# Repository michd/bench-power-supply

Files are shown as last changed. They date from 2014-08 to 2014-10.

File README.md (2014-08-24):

# Bench power supply

I'm working (currently just researching and prototyping) on developing my own bench power supply. This repository will mostly act as a working directory before it gets anywhere near completion, so expect stuff to move around a lot.

## Some requirements / desired features for the supply:

- DC output voltage of 1.5V - 35V (ish)
- Output current of up to 2.5~3A (ish)
- Voltage and current limit digitally adjustable, probably through rotary encoders
- Present output voltage and current displayed on LED 7 segment displays
- Additional (LCD?) display for setting the voltage and current limit (definitely need a way to view the current limit when it's not being reached)
- Maybe some USB ports (3?) providing 5V / 1A per port.

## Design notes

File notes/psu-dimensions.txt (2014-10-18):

Dimensions as seen from front; 0,0 is in top left

## IO board

Width: 119.1mm
Height: 56.7mm

Holes spacing:
Horizontal (width-wise): 113mm
Vertical (height-wise): 51.4mm
Diameter: 2mm
Margin around holes: 3mm

## Power board

Width:  99.2mm
Height: 74.4mm

Hole spacing:
Horizontal (width-wise): 90.2mm
Vertical (height-wise): 67.3mm
Diameter: 3mm
Margin around holes: 3.3mm

## Controller board

Width: 77.8mm
Height: 67.4mm

Holes spacing:
Horizontal (width-wise): 71.4mm
Vertical (height-wise): 61.6mm
Diameter: 2mm
Margin around holes: 2.5mm

## Main transformer

Width: 89.10mm
Height: 75.0mm
Depth: 64.2mm
Screwhole bottom offset: 8.5mm
Narrow side screwhole side offset: 8.5mm
Wide side screwhole side offset: 15.5mm
screwhole width: 4.5mm
Through-holes locations: 57.25x70.5mm, d: 5mm

# Box

inner Width: 150mm
inside holes: 154mm x 90mm  spacing
hole diameter: 154mm

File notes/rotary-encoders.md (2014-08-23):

These are just some notes to self after a session of figuring out how to get a rotary encoder do what I want. Thanks for the help, @james147
# Working with rotary encoders

For reading rotary encoders for input, use the [ClickEncoder](https://github.com/0xPIT/encoder/tree/arduino) library.

This library relies on [TimerOne](https://code.google.com/p/arduino-timerone/).

Each (click) rotary encoder requires 3 pins on the uC, two for the rotary encoder, one for the button. These pins can be any ol' digital input.

In `void loop()`, poll check encoder->getValue() to get the integer increase/decrease since last time. Base the integration on the example that comes with the library.

The input pins get pulled up on the arduino board, but it might need external pull-up resistors w/o the arduino board.

Also, and remember this: **the common is the middle pin**.

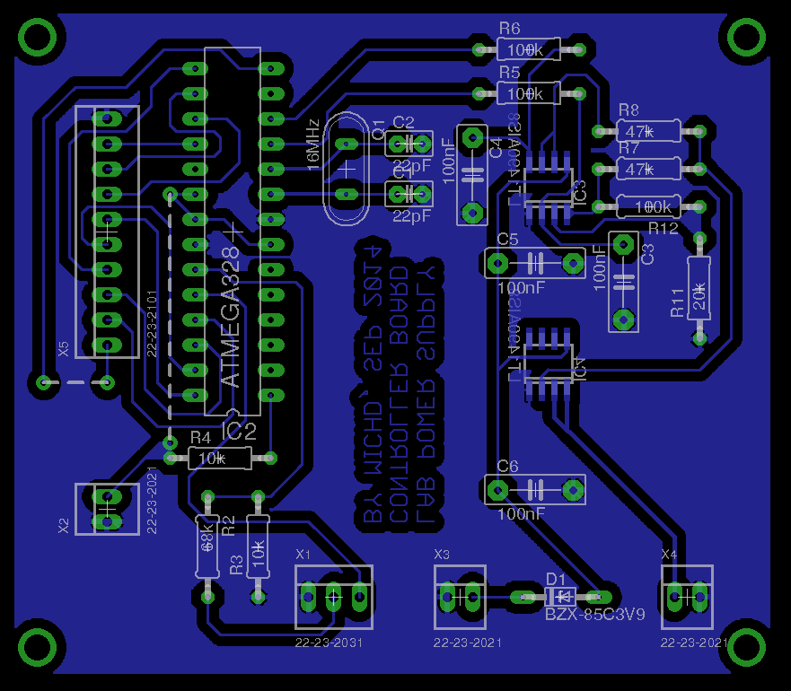
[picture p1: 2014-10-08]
eagle/controller_board_screenshot.png

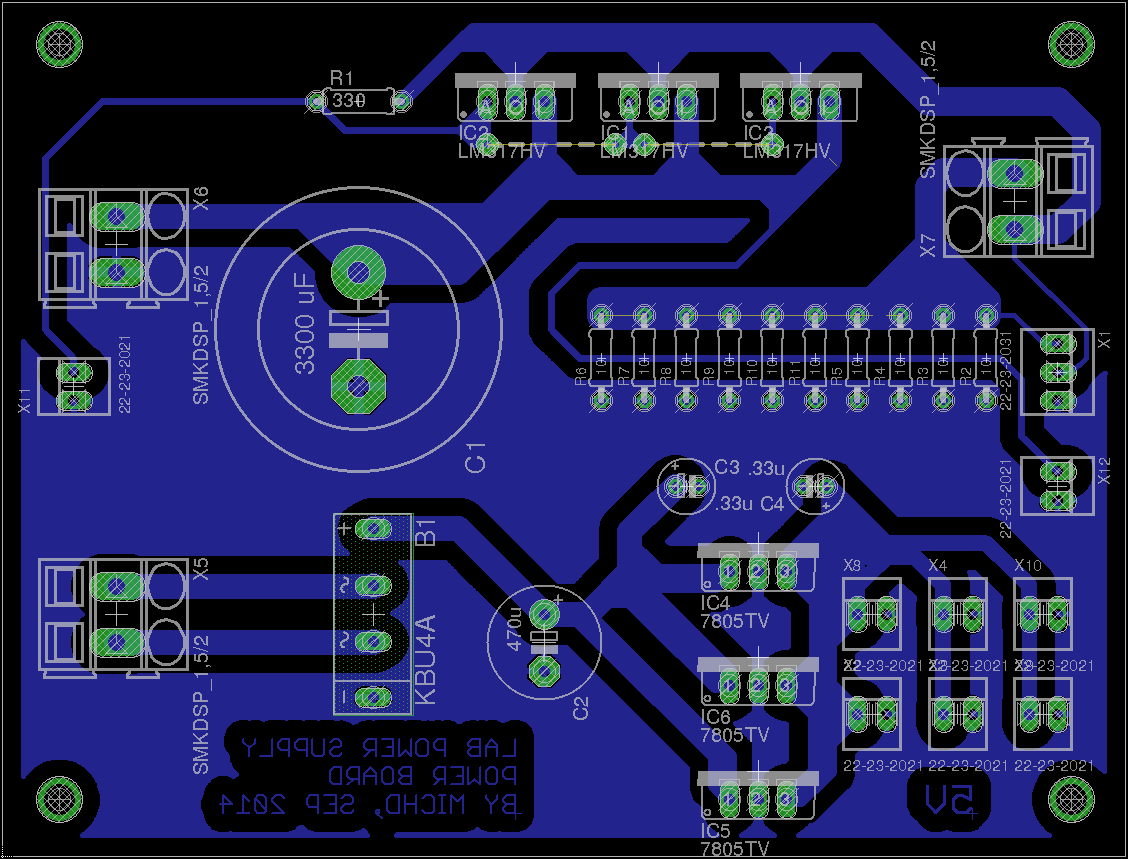
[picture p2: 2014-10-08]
eagle/power_board_screenshot.png

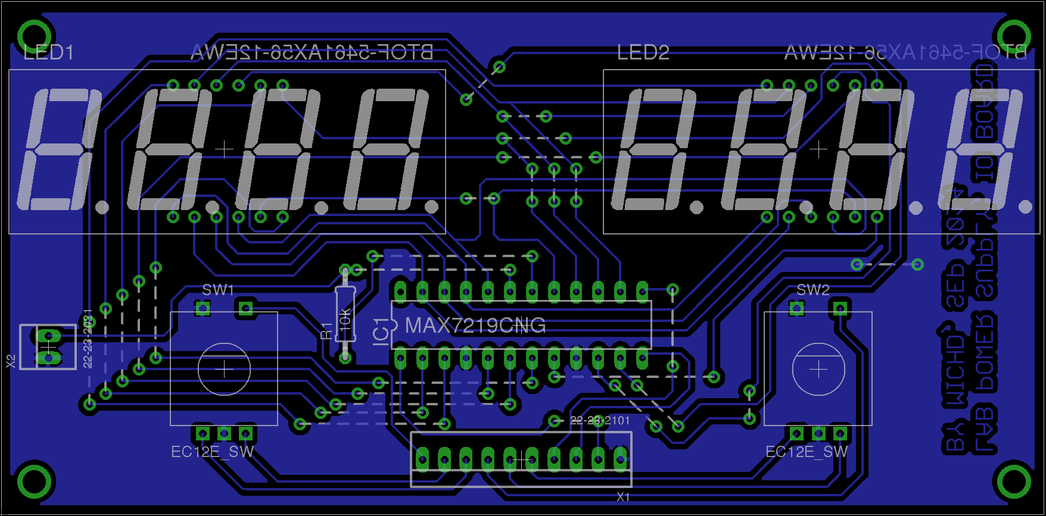
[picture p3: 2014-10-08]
eagle/io_board_screenshot.png

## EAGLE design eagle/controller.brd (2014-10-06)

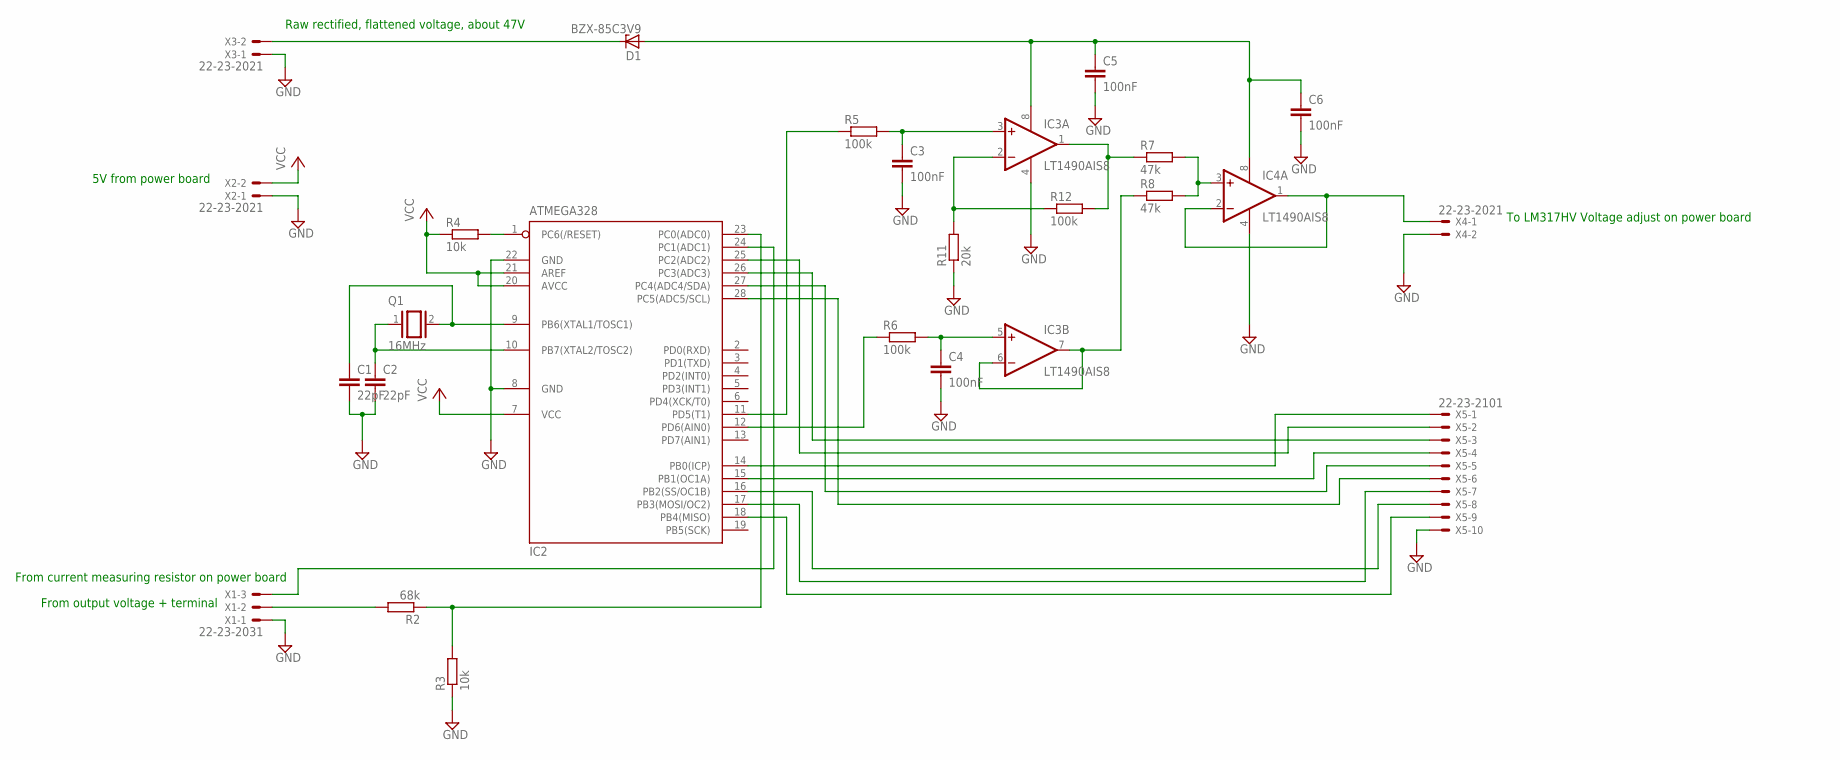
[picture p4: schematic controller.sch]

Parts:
C1, C2: 22pF; C2.5-2
C3, C4, C5, C6: 100nF; C7.5B3
D1: BZX-85C3V9; DO34Z7
IC2: ATMEGA328; DIL28-3
IC3, IC4: LT1490AIS8; SO08
Q1: 16MHz; QS
R2: 68k; 0207/10
R3, R4: 10k; 0207/10
R5, R6, R12: 100k; 0207/10
R7, R8: 47k; 0207/10
R11: 20k; 0207/10
X1: 22-23-2031
X2, X3, X4: 22-23-2021
X5: 22-23-2101

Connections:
GND: C1.2, C2.2, C3.2, C4.2, C5.2, C6.2, IC2.8 (GND), IC2.22 (GND), IC3.4 (V-), IC4.4 (V-), R3.1, R11.1, X1.1, X2.1, X3.1, X4.2, X5.10
unnamed: IC2.18 (PB4(MISO)), X5.9
unnamed: IC2.16 (PB2(SS/OC1B)), X5.8
unnamed: IC2.17 (PB3(MOSI/OC2)), X5.7
unnamed: IC2.7 (VCC), IC2.20 (AVCC), IC2.21 (AREF), R4.1, X2.2
unnamed: IC3.1 (OUT), R7.1, R12.2
unnamed: IC2.14 (PB0(ICP)), X5.1
unnamed: IC2.24 (PC1(ADC1)), X1.3
unnamed: IC2.23 (PC0(ADC0)), R2.1, R3.2
unnamed: R2.2, X1.2
unnamed: C1.1, IC2.9 (PB6(XTAL1/TOSC1)), Q1.2
unnamed: C2.1, IC2.10 (PB7(XTAL2/TOSC2)), Q1.1
unnamed: IC3.6 (-IN), IC3.7 (OUT), R8.1
unnamed: IC2.11 (PD5(T1)), R5.1
unnamed: IC2.1 (PC6(/RESET)), R4.2
unnamed: C3.1, IC3.3 (+IN), R5.2
unnamed: C4.1, IC3.5 (+IN), R6.2
unnamed: C5.1, C6.1, D1.A, IC3.8 (V+), IC4.8 (V+)
unnamed: IC2.12 (PD6(AIN0)), R6.1
unnamed: IC4.3 (+IN), R7.2, R8.2
unnamed: IC3.2 (-IN), R11.2, R12.1
unnamed: IC4.1 (OUT), IC4.2 (-IN), X4.1
unnamed: IC2.15 (PB1(OC1A)), X5.4
unnamed: IC2.25 (PC2(ADC2)), X5.2
unnamed: IC2.28 (PC5(ADC5/SCL)), X5.6
unnamed: IC2.27 (PC4(ADC4/SDA)), X5.5
unnamed: D1.C, X3.2
unnamed: IC2.26 (PC3(ADC3)), X5.3

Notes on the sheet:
5V from power board
Raw rectified, flattened voltage, about 47V
To LM317HV Voltage adjust on power board
From current measuring resistor on power board
From output voltage + terminal

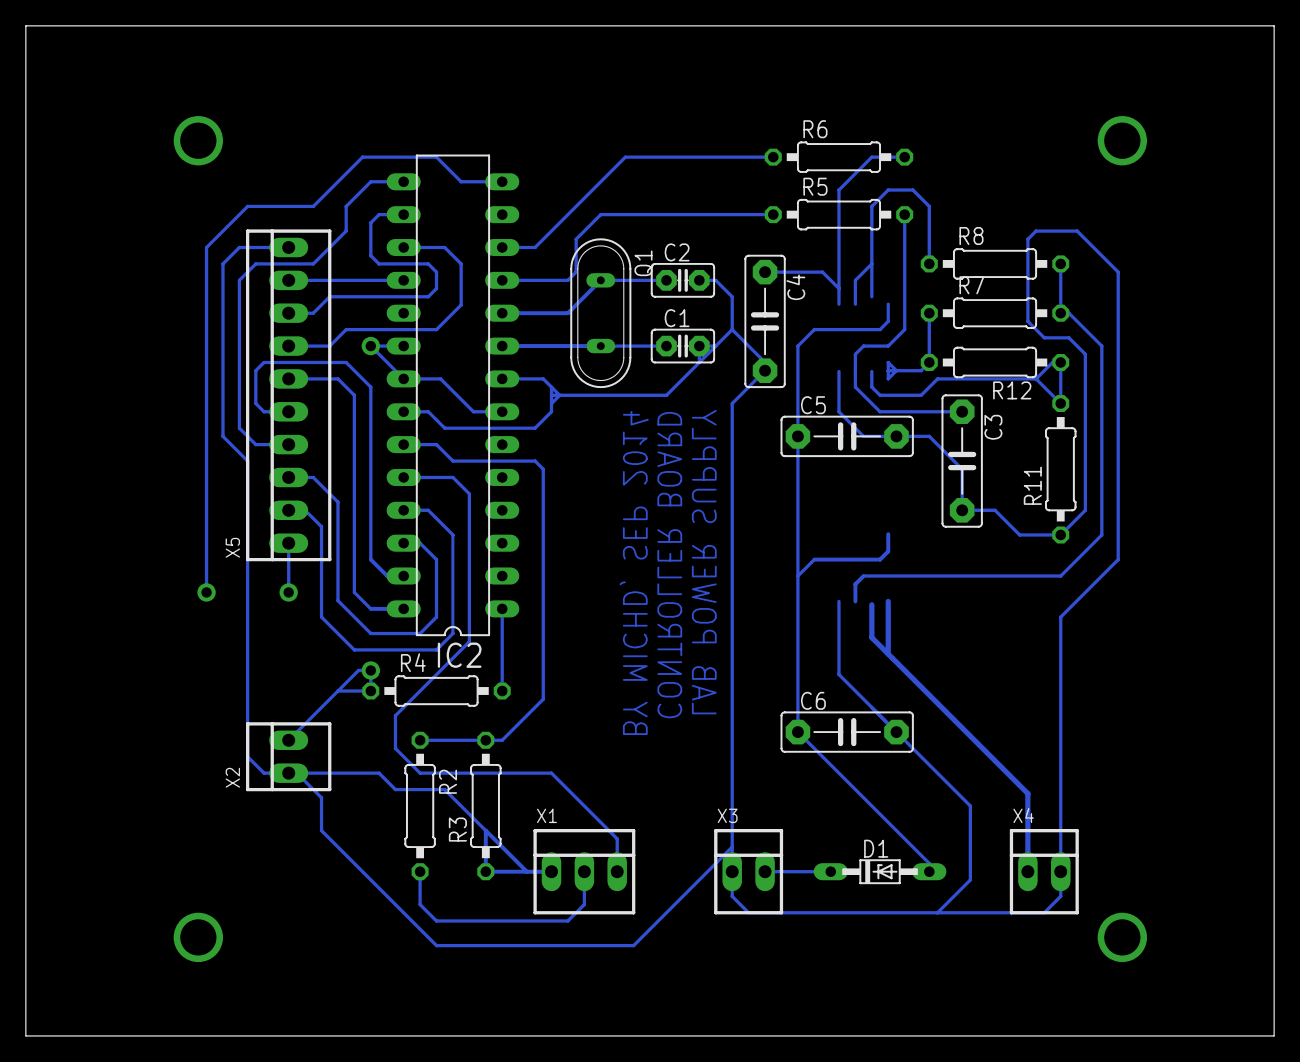
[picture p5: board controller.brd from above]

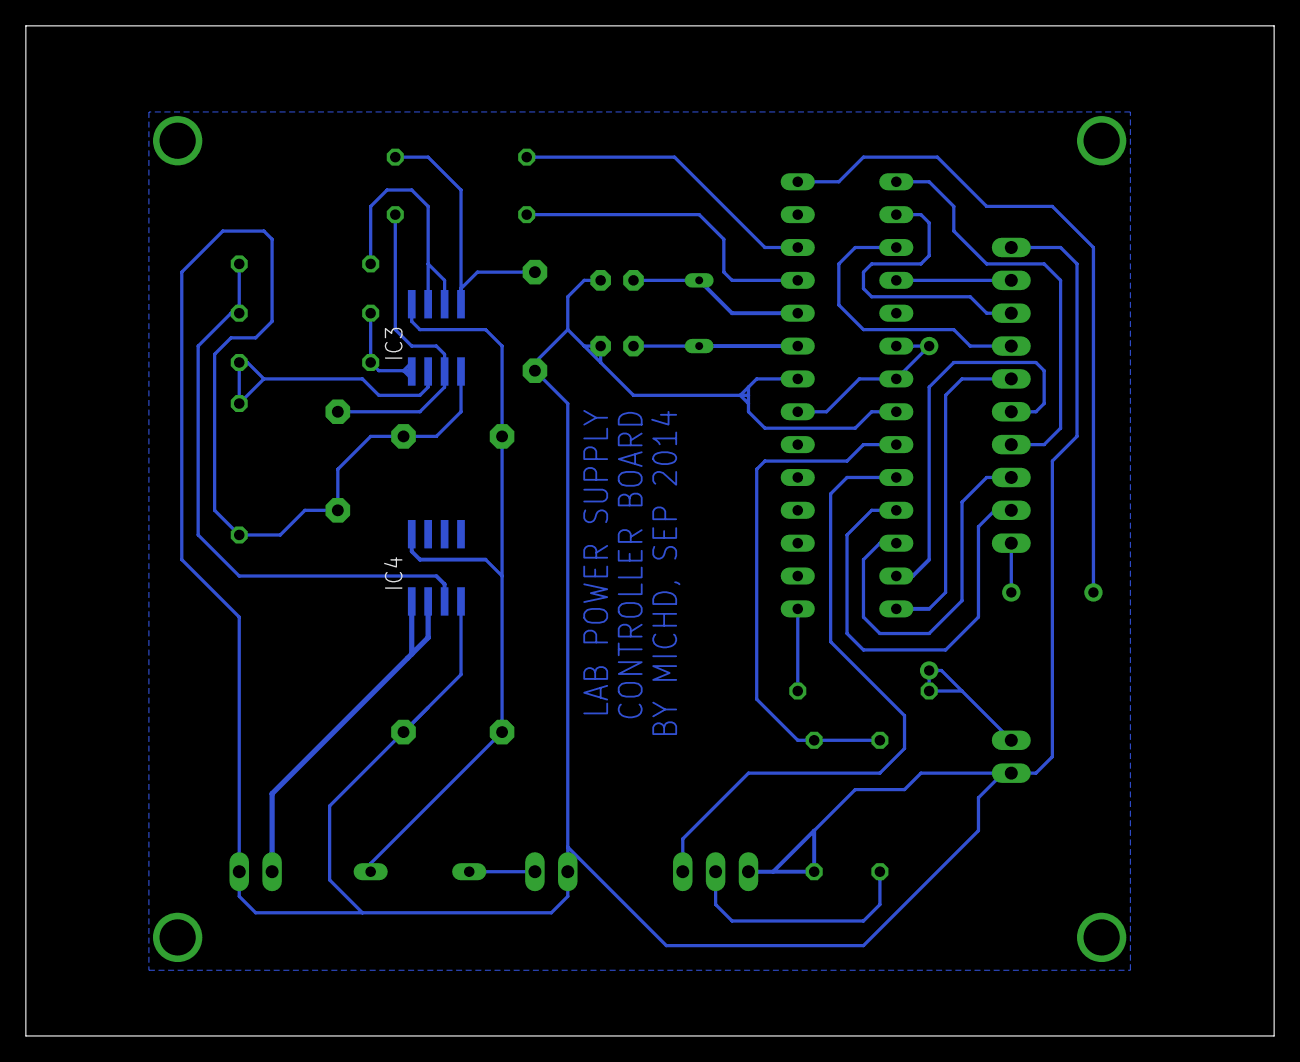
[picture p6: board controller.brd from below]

Board: 2 copper layers, 96.5 x 78.1 mm, 25 parts (2 on the bottom side), 28 nets.

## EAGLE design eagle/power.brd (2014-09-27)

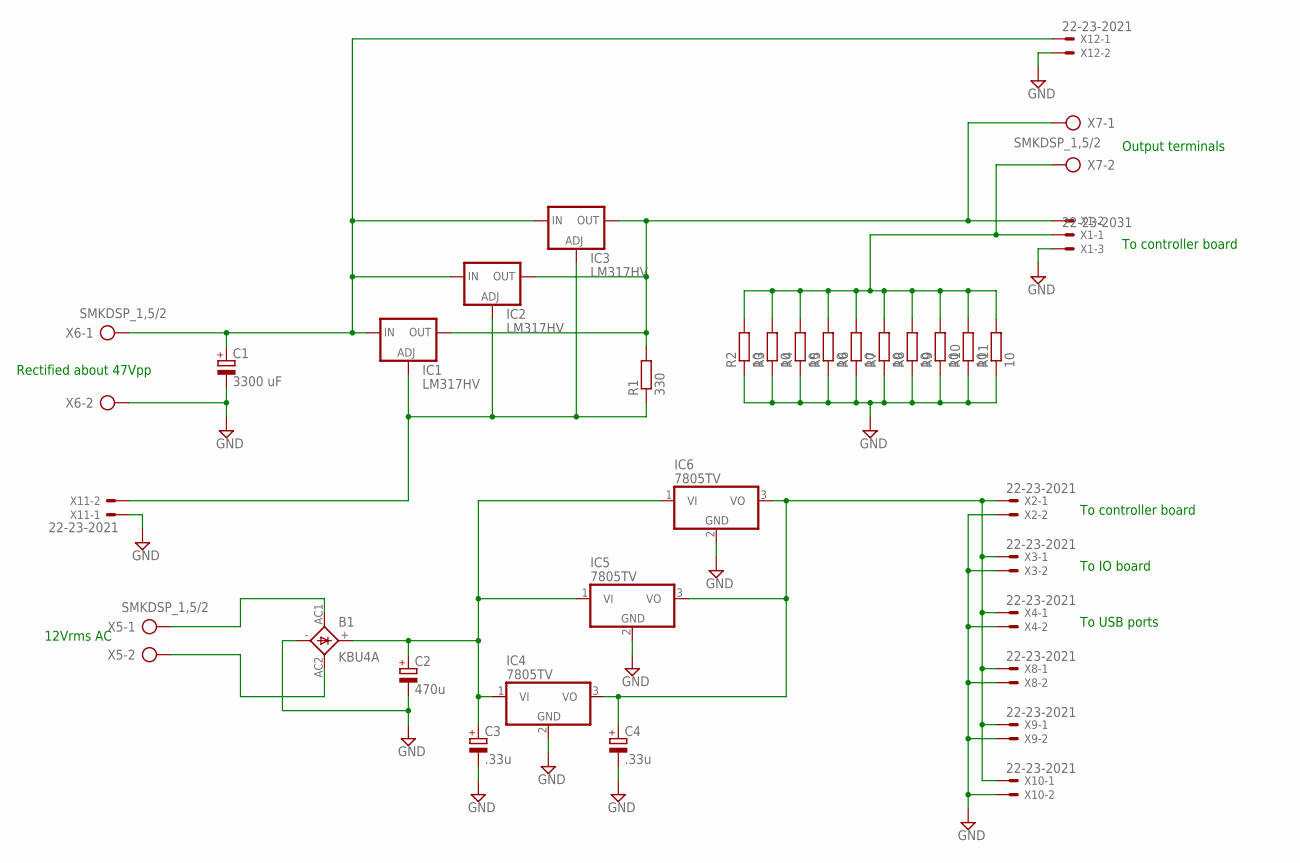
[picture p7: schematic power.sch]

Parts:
B1: KBU4A; 2KBB-R
C1: 3300 uF; EB25D
C2: 470u; E5-10,5
C3, C4: .33u; E2-5
IC1, IC2, IC3: LM317HV; 317TS
IC4, IC5, IC6: 7805TV; TO220V
R1: 330; 0207/7
R2, R3, R4, R5, R6, R7, R8, R9, R10, R11: 10; 0204/7
X1: 22-23-2031
X2, X3, X4, X8, X9, X10, X11, X12: 22-23-2021
X5, X6, X7: SMKDSP_1,5/2

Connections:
GND: B1.-, C1.-, C2.-, C3.-, C4.-, IC4.2 (GND), IC5.2 (GND), IC6.2 (GND), R2.1, R3.1, R4.1, R5.1, R6.1, R7.1, R8.1, R9.1, R10.1, R11.1, X1.3, X2.2, X3.2, X4.2, X6.2, X8.2, X9.2, X10.2, X11.1, X12.2
unnamed: B1.AC1, X5.1
unnamed: C1.+, IC1.3 (IN), IC2.3 (IN), IC3.3 (IN), X6.1, X12.1
unnamed: B1.AC2, X5.2
unnamed: IC1.2 (OUT), IC2.2 (OUT), IC3.2 (OUT), R1.2, X1.2, X7.1
unnamed: B1.+, C2.+, C3.+, IC4.1 (VI), IC5.1 (VI), IC6.1 (VI)
unnamed: C4.+, IC4.3 (VO), IC5.3 (VO), IC6.3 (VO), X2.1, X3.1, X4.1, X8.1, X9.1, X10.1
unnamed: IC1.1 (ADJ), IC2.1 (ADJ), IC3.1 (ADJ), R1.1, X11.2
unnamed: R2.2, R3.2, R4.2, R5.2, R6.2, R7.2, R8.2, R9.2, R10.2, R11.2, X1.1, X7.2

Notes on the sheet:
Rectified about 47Vpp
12Vrms AC
Output terminals
To controller board
To IO board
To USB ports

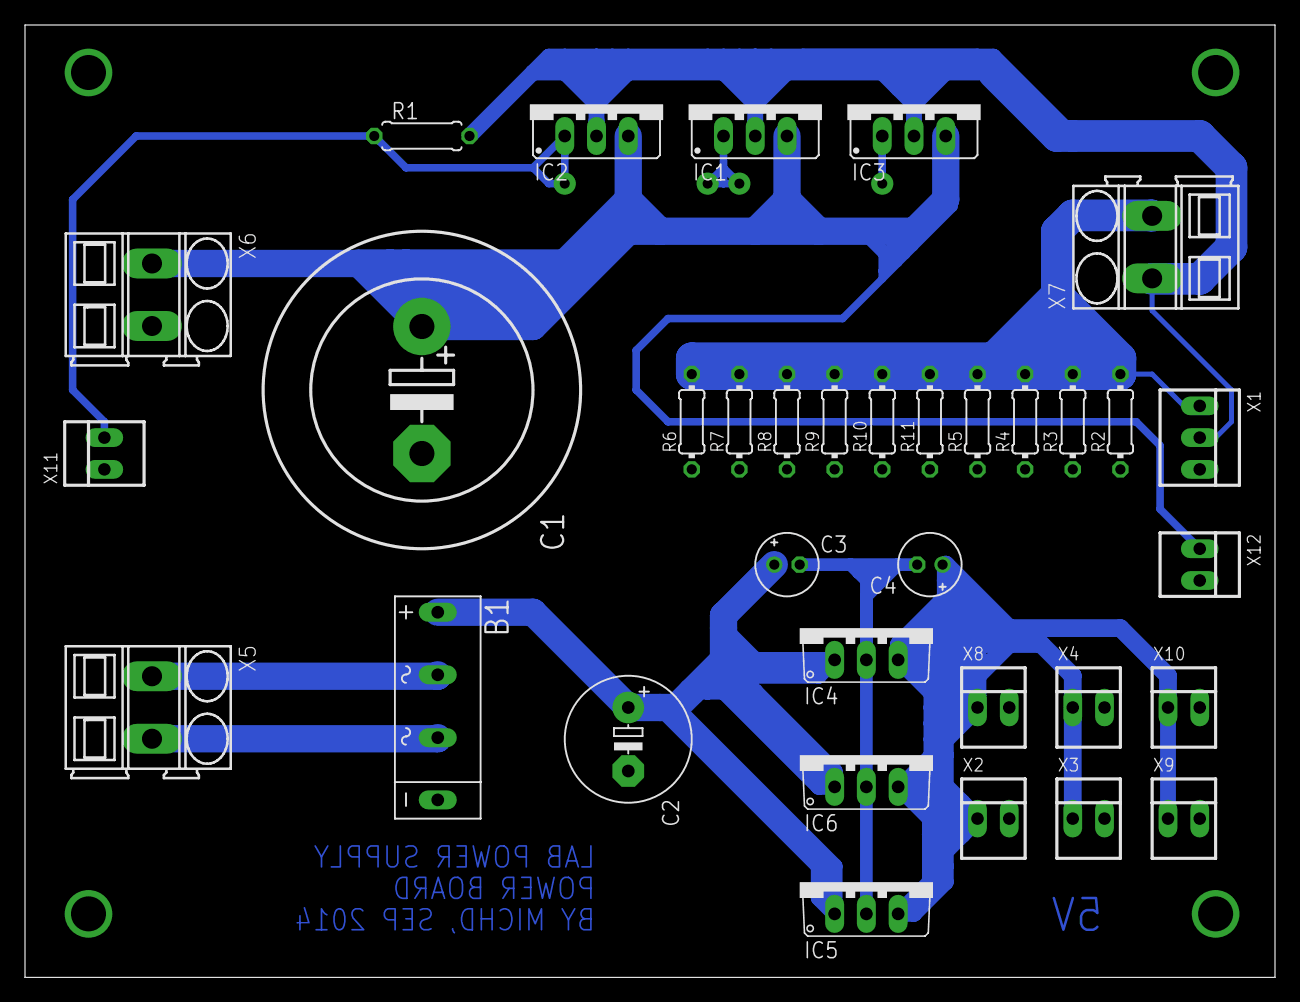
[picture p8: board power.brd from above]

Board: 2 copper layers, 100.0 x 76.2 mm, 34 parts (0 on the bottom side), 9 nets.

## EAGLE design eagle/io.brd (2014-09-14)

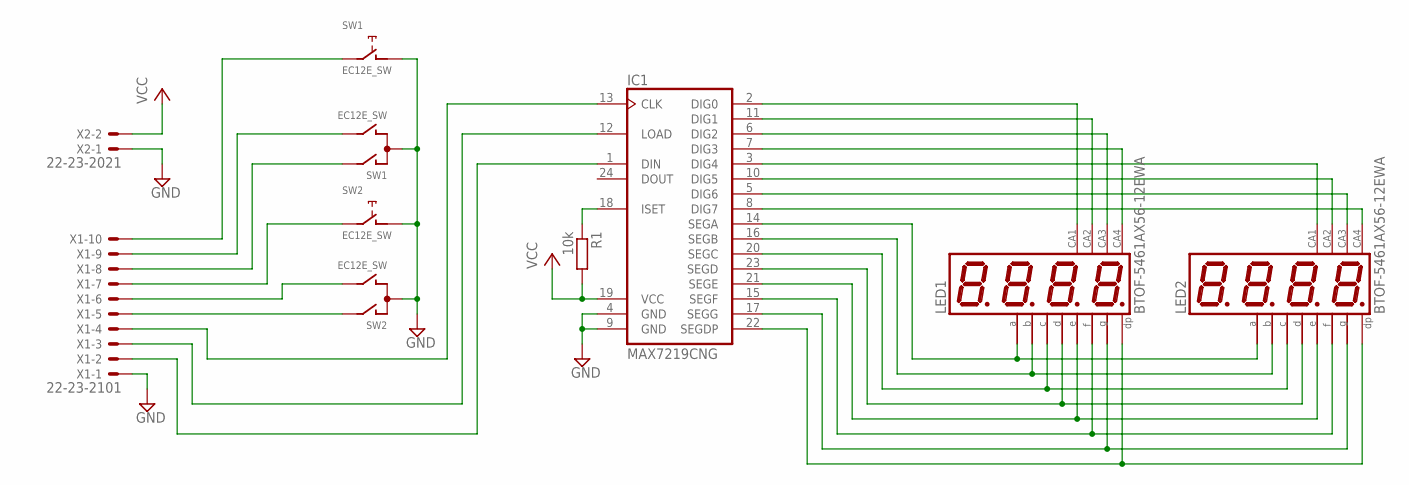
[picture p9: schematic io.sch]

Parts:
IC1: MAX7219CNG; DIL24-3
LED1, LED2: BTOF-5461AX56-12EWA; BX56-12
R1: 10k; 0207/10
SW1, SW2: EC12E_SW; ALPS_EC12E_SW
X1: 22-23-2101
X2: 22-23-2021

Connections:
GND: IC1.4 (GND), IC1.9 (GND), SW1.C, SW1.D (1), SW2.C, SW2.D (1), X1.1, X2.1
unnamed: IC1.12 (LOAD), X1.3
unnamed: IC1.2 (DIG0), LED1.12 (CA)
unnamed: IC1.11 (DIG1), LED1.9 (CA)
unnamed: IC1.6 (DIG2), LED1.8 (CA)
unnamed: IC1.3 (DIG4), LED2.12 (CA)
unnamed: IC1.5 (DIG6), LED2.8 (CA)
unnamed: IC1.8 (DIG7), LED2.6 (CA)
unnamed: IC1.16 (SEGB), LED1.7 (B), LED2.7 (B)
unnamed: IC1.20 (SEGC), LED1.4 (C), LED2.4 (C)
unnamed: IC1.23 (SEGD), LED1.2 (D), LED2.2 (D)
unnamed: IC1.21 (SEGE), LED1.1 (E), LED2.1 (E)
unnamed: IC1.15 (SEGF), LED1.10 (F), LED2.10 (F)
unnamed: IC1.13 (CLK), X1.4
unnamed: IC1.18 (ISET), R1.1
unnamed: IC1.17 (SEGG), LED1.5 (G), LED2.5 (G)
unnamed: IC1.22 (SEGDP), LED1.3 (DP), LED2.3 (DP)
unnamed: IC1.1 (DIN), X1.2
unnamed: IC1.14 (SEGA), LED1.11 (A), LED2.11 (A)
unnamed: IC1.10 (DIG5), LED2.9 (CA)
unnamed: SW2.E (2), X1.7
unnamed: SW1.E (2), X1.10
unnamed: SW1.B, X1.9
unnamed: SW2.A, X1.5
unnamed: SW2.B, X1.6
unnamed: SW1.A, X1.8
unnamed: IC1.7 (DIG3), LED1.6 (CA)
VCC: IC1.19 (VCC), R1.2, X2.2

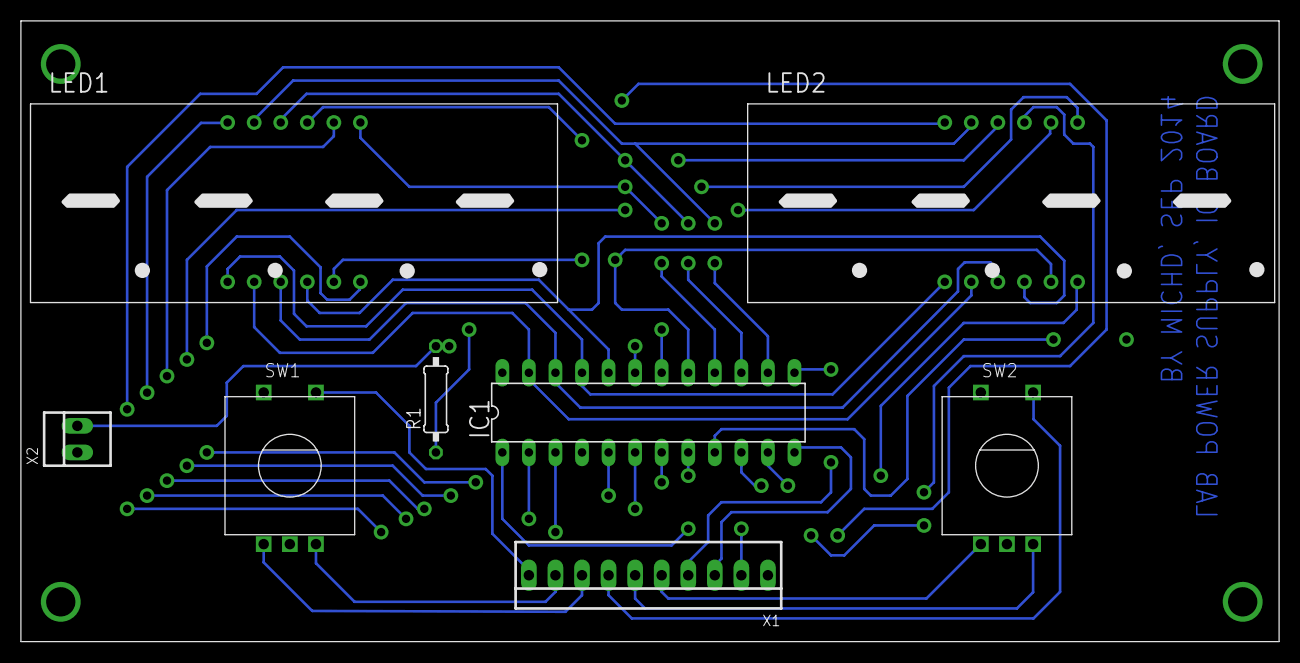
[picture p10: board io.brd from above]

Board: 2 copper layers, 120.3 x 59.4 mm, 8 parts (0 on the bottom side), 28 nets.

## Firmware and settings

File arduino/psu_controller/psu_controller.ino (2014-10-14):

#include "LedControl.h"
#include "ClickEncoder.h"
#include "TimerOne.h"

// # Configuration
// uC properties
#define ADC_REFERENCE_VOLTAGE 5.0
#define ADC_PRECISION 1024
#define PWM_PRECISION 255.0

// Display properties
// Display brightness, 0x0-0xF
#define DISP_INTENSITY 0x8
// Number of digits available per display
#define DISP_DIGITS 4

// Voltage control
// According to the datasheet this offset should be 1.30V max,
// but in practice I needed some more
#define REGULATOR_VOLTAGE_OFFSET 2.25

//Output voltage is controlled with 2 PWM outputs that get summed,
//Because of PWM precision limitations
#define COARSE_VOLTAGE_RANGE 29.170
#define FINE_VOLTAGE_RANGE 5.0

// Voltage precision of the PSU in Volts,
// used for rounding measured voltage and stepping through configured voltage
#define VOLTAGE_STEP 0.05
// Used for display point
#define VOLTAGE_DECIMAL_POINTS 2
// Some software limits here, 2.5 because of REGULATOR_VOLTAGE_OFFSET
// and rounding
#define VOLTAGE_TARGET_MINIMUM 2.5
#define VOLTAGE_TARGET_MAXIMUM 35.0
// Voltage that gets set on system startup
#define VOLTAGE_TARGET_INIT 5

// Current precision of the PSU in Amps,
// used for rounding measurements and stepping through current limit value
#define CURRENT_STEP 0.005
// Used for display point
#define CURRENT_DECIMAL_POINTS 3
// Some software limits here
#define CURRENT_TARGET_MINIMUM 0.0
#define CURRENT_TARGET_MAXIMUM 2.5
// Current limit that gets set on system startup
#define CURRENT_TARGET_INIT 0.25

// Circumvents advancing two units per notch when turning rotary encoder:
#define UNITS_PER_ENCODER_NOTCH 1

// MAX7219CNG sees our two displays as a single 8-digit one, so:
// Digit index where voltage display starts
#define VOLTAGE_DISP_OFFSET 0
// Digit index where current display starts
#define CURRENT_DISP_OFFSET DISP_DIGITS

// Fine-tune these for measuring calibration
// Resistance in series with load through which current is measured
// When measured with a multimeter, this would've been 1.015, yet
// actual calibration came up with this value.
#define CURRENT_MEASURING_RESISTANCE 0.788
// Measured voltage is voltage-divided to stay within the ADC_REFERENCE VOLTAGE
#define VOLTAGE_MEASURING_MULTIPLIER 9.4

// For the main loop()
#define LOOP_CYCLE_DELAY 100

// When in setting mode on a display, revert back to measurement
// after this many ms
#define SETTING_DISP_TIMEOUT 3000

// These cycles are used for blinking the display out when in setting mode
#define DISPLAY_CYCLES 4

// # Pins
// Legend: [A|PWM]<O|I>_<name>
// A = analog (for inputs)
// PWM = pulse width modulation output
// O = output
// I = input
// I/O board
#define O_DISP_DATA_IN 12
#define O_DISP_CLOCK   11
#define O_DISP_LOAD    10
#define I_ROTA_VOLTAGE A2
#define I_ROTB_VOLTAGE A3
#define I_BTN_VOLTAGE   8
#define I_ROTA_CURRENT A4
#define I_ROTB_CURRENT A5
#define I_BTN_CURRENT   9

// Voltage / current measuring
#define AI_MEASURE_VOLTAGE A0
#define AI_MEASURE_CURRENT A1

// Voltage control PWM
#define PWMO_VOLTAGE_COARSE 5
#define PWMO_VOLTAGE_FINE   6

enum displayMode {
  measuring,
  setting
};

LedControl disp = LedControl(
  O_DISP_DATA_IN,
  O_DISP_CLOCK,
  O_DISP_LOAD,
  1  
);

ClickEncoder *voltageKnob;
ClickEncoder *currentKnob;

// Voltage meant to be output (V)
float targetVoltage;
// Current to limit to. output voltage can and will be lowered
// to enforce this limit. (A)
float targetCurrentLimit;

// Latest output voltage measurement (V)
float voltageMeasurement;

// Latest output current measurement (A)
float currentMeasurement;


displayMode voltageDisplayMode = measuring;
displayMode currentDisplayMode = measuring;

// Remaining time before display goes back to measurement mode when in setting mode
int voltageDisplayModeTimeout = 0;
int currentDisplayModeTimeout = 0;

//Used for blinking display when in setting mode
char displayCycleStep = 0;

//==================================================================

// Bugs to fix after initial round of testing:
// - Setting current limit to 0 breaks limit, raises voltage
// - Clicking current button doesn't do anything (should toggle display mode)
// - Measurements on display look very jittery, changing up to .25 every frame
// - More calibrating needs to be done

//==================================================================

void readInputs() {
  voltageKnob->service();
  currentKnob->service();
  
  currentMeasurement = readCurrent();
  voltageMeasurement = readVoltage();
  adjustOutput();
}

void setup() {  
  // Initialize rotary encoders
  voltageKnob = new ClickEncoder(
    I_ROTA_VOLTAGE,
    I_ROTB_VOLTAGE,
    I_BTN_VOLTAGE
  );
  
  voltageKnob->setAccelerationEnabled(true);
  
  currentKnob = new ClickEncoder(
    I_ROTA_CURRENT,
    I_ROTB_CURRENT,
    I_BTN_CURRENT
  );
  
  // Configure display
  disp.setIntensity(0, DISP_INTENSITY);
  disp.clearDisplay(0);
  
  targetVoltage = VOLTAGE_TARGET_INIT;
  targetCurrentLimit = CURRENT_TARGET_INIT;
  
  // Set up timer for reading rotary encoders
  // and voltage/current measurements
  Timer1.initialize(1000);
  Timer1.attachInterrupt(readInputs);
  
  //Pin modes for measuring voltage and current
  pinMode(AI_MEASURE_VOLTAGE, INPUT);
  pinMode(AI_MEASURE_CURRENT, INPUT);
  
  // Pin modes for PWM outputs for controller voltage and current
  pinMode(PWMO_VOLTAGE_COARSE, OUTPUT);
  pinMode(PWMO_VOLTAGE_FINE, OUTPUT); 

  // Makes displays work for some reason.
  // TODO: figure out why and elimate need for Serial in here
  Serial.begin(9600);
}

void loop() {
  int voltageKnobDiff = (int)(voltageKnob->getValue() / UNITS_PER_ENCODER_NOTCH);
  int currentKnobDiff = (int)(currentKnob->getValue() / UNITS_PER_ENCODER_NOTCH);
  
  voltageKnobDiff *= abs(voltageKnobDiff);
  currentKnobDiff *= abs(currentKnobDiff);
  
  // Voltage knob moved
  if (voltageKnobDiff != 0) {    
    voltageDisplayMode = setting; 
    adjustTargetVoltage(voltageKnobDiff);
    voltageDisplayModeTimeout = SETTING_DISP_TIMEOUT;
  }
  
  // Voltage knob button clicked
  if (voltageKnob->getButton() == ClickEncoder::Clicked) {
    if (voltageDisplayMode == setting) {
      voltageDisplayMode = measuring;
      voltageDisplayModeTimeout = 0;
    } else {
      voltageDisplayMode = setting;
      voltageDisplayModeTimeout = SETTING_DISP_TIMEOUT;
    }
  }
  
  // Current knob moved
  if (currentKnobDiff != 0) {
    currentDisplayMode = setting;
    adjustTargetCurrentLimit(currentKnobDiff);
    currentDisplayModeTimeout = SETTING_DISP_TIMEOUT;
  }
  
  // Current knob button clicked
  if (currentKnob->getButton() == ClickEncoder::Clicked) {
    if (currentDisplayMode == setting) {
      currentDisplayMode = measuring;
      currentDisplayModeTimeout = 0;
    } else {
      currentDisplayMode = setting;
      currentDisplayModeTimeout = SETTING_DISP_TIMEOUT;
    }
  }
  
  updateDisplays();

  delay(LOOP_CYCLE_DELAY);
}

/**
 * Adjust the target voltage by a given number of steps
 *
 * Constrains the target voltage to a minimum and maximum
 */
void adjustTargetVoltage(int steps) {
  targetVoltage += (steps * VOLTAGE_STEP);
  if (targetVoltage < VOLTAGE_TARGET_MINIMUM) targetVoltage = VOLTAGE_TARGET_MINIMUM;
  if (targetVoltage > VOLTAGE_TARGET_MAXIMUM) targetVoltage = VOLTAGE_TARGET_MAXIMUM;
}

/**
 * Adjust the target current limit by a given number of steps
 *
 * Constrains the target current to a minimum and maximum
 */
void adjustTargetCurrentLimit(int steps) {
  targetCurrentLimit += (steps * CURRENT_STEP);
  if (targetCurrentLimit < CURRENT_TARGET_MINIMUM) targetCurrentLimit = CURRENT_TARGET_MINIMUM;
  if (targetCurrentLimit > CURRENT_TARGET_MAXIMUM) targetCurrentLimit = CURRENT_TARGET_MAXIMUM;
}

/**
 * Reads voltage from analog input and translates it to the
 * actual voltage value.
 *
 * Also depends on readCurrent, as the voltage drop over the
 * current measuring resistors needs to be subtracted from
 * the voltage read.
 * 
 * Value from ADC ranges 0-1023, which maps to 0-39V at 
 * 0.038V precision.
 * 
 * Value is rounded to the nearest 0.05V.
 */
float readVoltage() {
  int inputValue = analogRead(AI_MEASURE_VOLTAGE);
  
  return (
      (
        (float) inputValue /
        (ADC_PRECISION / ADC_REFERENCE_VOLTAGE)
      ) *
      VOLTAGE_MEASURING_MULTIPLIER // That is, voltage divider ratio
    ) -
    currentMeasurement * CURRENT_MEASURING_RESISTANCE;
}

/**
 * Reads voltage from analog input and translates it to the
 * actual current value.
 *
 * Value from ADC technically ranges 0-1023, which maps to 0-5A at
 * 0.005 precision, which we'll keep.
 *
 * Actual values should not go far beyond 2.5A. Software limited.
 */
float readCurrent() {
  int inputValue = analogRead(AI_MEASURE_CURRENT);
  
  return (           
      (float) inputValue / 
      (ADC_PRECISION / ADC_REFERENCE_VOLTAGE) 
    ) / 
    CURRENT_MEASURING_RESISTANCE;
}

/**
 * Intermediate function for writeVoltage, adjusts voltage for current limiting
 */
void adjustOutput() {
  float outputVoltage = targetVoltage;
  float currentMeasuringVoltageDrop = (float) (currentMeasurement * CURRENT_MEASURING_RESISTANCE);
  float estimatedLoadResistance = voltageMeasurement / currentMeasurement;
  
  // Adjust for current limit 
  if (targetCurrentLimit - currentMeasurement < -CURRENT_STEP) {
      outputVoltage = (targetCurrentLimit * estimatedLoadResistance) + 
                      (targetCurrentLimit * CURRENT_MEASURING_RESISTANCE);
  } else {
    // Adjust for current measuring resistor voltage drop
    // This might need tweaking depending on stability of the analog input measurements
    if (targetVoltage - voltageMeasurement > VOLTAGE_STEP || currentMeasuringVoltageDrop > VOLTAGE_STEP) {
      outputVoltage += currentMeasuringVoltageDrop;
    }
  }
  writeVoltage(outputVoltage);
}
  

/**
 * Sets the control voltage, connected to voltage adjust pins on
 * regulators.
 */
void writeVoltage(float voltage) {
  voltage -= (float) REGULATOR_VOLTAGE_OFFSET;
   
  int coarse = (int)voltage;
  float fine;
  if (coarse > COARSE_VOLTAGE_RANGE) coarse -= (coarse - COARSE_VOLTAGE_RANGE);
  
  fine = voltage - (float) coarse;
  writeCoarseVoltage(coarse);
  writeFineVoltage(fine);
}

void writeCoarseVoltage(int cVoltage) {
  int cAnalog = (int) ((PWM_PRECISION / (float) COARSE_VOLTAGE_RANGE) * cVoltage);
  analogWrite(PWMO_VOLTAGE_COARSE, cAnalog);  
}

void writeFineVoltage(float fVoltage) {
  int fAnalog = (int) ((PWM_PRECISION / (float) FINE_VOLTAGE_RANGE) * fVoltage);
  analogWrite(PWMO_VOLTAGE_FINE, fAnalog);
}

// ########################################################
// ## Format and display voltage and current on displays ##
// ########################################################

/**
 * Updates voltage and current displays with their relevant values.
 *
 * Takes into account whether the display is in measure or setting mode
 * When in setting mode: 
 *   - Blinks the display out every 5 times this is called
 *   - Reverts to measurement mode after a timeout
 */
void updateDisplays() {
  // Voltage display mode control
  if (voltageDisplayMode == setting) {
    voltageDisplayModeTimeout -= LOOP_CYCLE_DELAY;
    if (voltageDisplayModeTimeout <= 0) {
      voltageDisplayModeTimeout = 0;
      voltageDisplayMode = measuring;
    }
  }
  
  // Current display mode control
  if (currentDisplayMode == setting) {
    currentDisplayModeTimeout -= LOOP_CYCLE_DELAY;
    if (currentDisplayModeTimeout <= 0) {
      currentDisplayModeTimeout = 0;
      currentDisplayMode = measuring;
    }
  }
  
  // Voltage display
  if (voltageDisplayMode == setting) {
    if (displayCycleStep == 0) {
      clearDisplay(VOLTAGE_DISP_OFFSET);
    } else {
      displayVoltage(targetVoltage);
    }
  } else {
    displayVoltage(voltageMeasurement);
  }
  
  // Current display
  if (currentDisplayMode == setting) {
    if (displayCycleStep == 0) {
      clearDisplay(CURRENT_DISP_OFFSET);
    } else {
      displayCurrent(targetCurrentLimit);
    }
  } else {
    displayCurrent(currentMeasurement);
  }
  
  // Advance display cycle
  displayCycleStep += 1;
  if (displayCycleStep == DISPLAY_CYCLES) displayCycleStep = 0;
}

/**
 * Shows a given float voltage value on the relevant display.
 * 
 * Displays in format [X]X.XX
 * @todo Fix bug where first digit remains when no update is available
 *       Should be blanked instead.
 */
void displayVoltage(float voltage) {
  float roundedVoltage = roundToNearest(voltage, VOLTAGE_STEP);
  signed char digits[DISP_DIGITS];
  prepareForDisplay(roundedVoltage, VOLTAGE_DECIMAL_POINTS, digits);
  writeDisplay(VOLTAGE_DISP_OFFSET, VOLTAGE_DECIMAL_POINTS, digits);
}

/**
 * Shows a given float current value on the relevant display.
 *
 * Display it in format X.XXX
 */
void displayCurrent(float current) {
  float roundedCurrent = roundToNearest(current, CURRENT_STEP);
  signed char digits[DISP_DIGITS];
  prepareForDisplay(roundedCurrent, CURRENT_DECIMAL_POINTS, digits);
  writeDisplay(CURRENT_DISP_OFFSET, CURRENT_DECIMAL_POINTS, digits);
}

void writeDisplay(char displayOffset, char decimalPoints, signed char* digits) {
  char i;
  disp.shutdown(0, true);
  
  for(i = 0; i < DISP_DIGITS; i += 1) {     
    disp.setChar(
      0,
      i + displayOffset,
      (digits[i] == -1 ? ' ' : digits[i]),
      i == DISP_DIGITS - (decimalPoints + 1)
    );
  }
  
  disp.shutdown(0, false);
}

/**
 * Clear a single display by writing space characters to every digit
 */
void clearDisplay(char displayOffset) {
  char i;
  disp.shutdown(0, true);
  
  for(i = 0; i < DISP_DIGITS; i++) disp.setChar(0, i + displayOffset, ' ', false);
  
  disp.shutdown(0, false);
}

char getCharDigit(signed char digit)
{
  switch(digit)
  {
    case -1: return ' ';
    case 0: return '0';
    case 1: return '1';
    case 2: return '2';
    case 3: return '3';
    case 4: return '4';
    case 5: return '5';
    case 6: return '6';
    case 7: return '7';
    case 8: return '8';
    case 9: return '9';
  }
}

/**
 * Rounds a float value to the nearest <rounding>
 * 
 * Used to round voltage and current measurements to 0.05V and 0.005A
 *
 * @note Only works somewhat reliably with roundings ending in 5
 * @todo Investigate using some stdlib stuff to make this neater,
 *       yet still not riddled with floating point errors.
 */
float roundToNearest(float input, float rounding) {
  int preMultiplier = 1;
  int intVersion;

  if (rounding < 1)  preMultiplier = 10;
  if (rounding < 0.1) preMultiplier = 100;
  if (rounding < 0.01) preMultiplier = 1000;

  intVersion = (int)(input * preMultiplier);

  int intDivided = (int)((float)intVersion / (rounding * preMultiplier));
  int remainderInt = (((float)intVersion / (rounding * preMultiplier)) - intDivided) * 10;

  int roundingLeftOver = (int)((float)remainderInt / (rounding * preMultiplier));
  float roundingRemainder = ((float)remainderInt / (rounding * preMultiplier)) - roundingLeftOver;

  if (roundingRemainder >= ((rounding * preMultiplier) / 2)) roundingLeftOver += 1;

  int result = (intDivided * (rounding * preMultiplier)) + (roundingLeftOver * (rounding * preMultiplier)); 
  return (float)result / preMultiplier;
}

/**
 * Retrieves digits from a float value, in an array of chars
 * 
 * Used for preparing to display float values on 7-segment displays
 */
void prepareForDisplay(float input, char decimalPoints, signed char* outDigits) {
  int intInput = (int)(((int)(input * power(10, decimalPoints))) % power(10, DISP_DIGITS));
  char i;
  signed char digit;
  for (i = DISP_DIGITS - 1; i >= 0; i--) {
    digit = (signed char)(((intInput % power(10, i + 1)) - (intInput % power(10, i))) / power(10, i));
    // Don't display a digit at [X]x.xx if [X] is 0
    if (digit == 0 && i == (decimalPoints + 1)) digit = -1;
    outDigits[DISP_DIGITS - i - 1] = getCharDigit(digit);
  }
}

/**
 * Integer implementation of pow
 */
int power(int base, int exp) {
  int i, result;

  if (exp == 0) return 1;

  result = base;

  for (i = 1; i < exp; i++) result *=  base;

  return result;
}

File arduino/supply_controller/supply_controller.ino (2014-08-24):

// IMPORTANT NOTE:
// I refactored my initial sketchy code, but this was only after
// I'd broken down the breadboarded test setup (the beast had 54 wires!)
// What I'm saying is that I can't promise this works.
// This was on an Arduino Uno r3, with an atmega328.

// You can find the LedControl library here: http://playground.arduino.cc/Main/LedControl
// (Download is somewhere near the bottom of the page)
#include "LedControl.h"

// Pins for the MAX7219 serial interface
#define P_LED_DISPLAY_DATA_IN 12
#define P_LED_DISPLAY_CLK 11
#define P_LED_DISPLAY_LOAD 10
// LED intensity, Range of 0x0-0xF, where 0xF is brightest
#define LED_DISPLAY_INTENSITY 0x8
// Interval in ms
#define LED_DISPLAY_UPDATE_INTERVAL 250

// ADC input pins
#define P_MEASURE_VOLTAGE A0
#define P_MEASURE_CURRENT A1

// LedControl instance for the two 4-digit 7-segment displays
LedControl lc = LedControl(
      P_LED_DISPLAY_DATA_IN,
      P_LED_DISPLAY_CLK,
      P_LED_DISPLAY_LOAD,
      1
    );


void setup() {  
  pinMode(P_MEASURE_VOLTAGE, INPUT);
  pinMode(P_MEASURE_CURRENT, INPUT);
  
  // Setup display
  lc.setIntensity(0, LED_DISPLAY_INTENSITY); //0-15
  lc.clearDisplay(0);
}

void loop() {
  writeNumber(readVoltage(), 0);
  writeNumber(readCurrent(), 1);
  // Yeah, this isn't going to stay.
  delay(LED_DISPLAY_UPDATE_INTERVAL);
}

/**
 * Reads the present output voltage from the ADC and
 * converts it to the actual base-10 value in Volts.
 *
 * Voltage is measured through a voltage divider,
 * bringing it down from 39V to a scale of 0-5V,
 * suitable for the analog to digital converter.
 * 
 * It is converted from the chip's 0-1023 scale to an
 * actual voltage level, and then multiplied to be on
 * the correct scale.
 *
 * @return {float}
 * @todo Reform formula to use a well-named constant for calibration
 */
float readVoltage() {
  int inputValue = analogRead(P_MEASURE_VOLTAGE); //0-1023
  return ((float) (inputValue)) / 26.23;
}

/**
 * Reads the present output current from the ADC and
 * converts it to the actual base-10 value in Amperes.
 *
 * Current is measured by placing a ~1ohm resistor in series
 * with the load, and then measuring the voltage across this
 * 1 ohm resistor.
 * 
 * Since we're dealing with well under 5 amps, this doesn't
 * require a voltage divider.
 *
 * @return {float}
 * @todo Reform formula to use a well-named constant for calibration
 */
float readCurrent() {
  int inputValue = analogRead(P_MEASURE_CURRENT); // 0-1023
  return (((float) (inputValue)) / 265.0);
}

/**
 * Writes a number on a 4-digit display. Range: 0.00-99.99
 *
 * @param {float} number
 * @param {int} displayIndex - signifies a 4 digit display
 * @todo allow setting of number of decimal places
 * @todo use an array of digits instead of badly named vars
 */
void writeNumber(float number, int displayIndex) {
  int tens = 0;
  int ones = 0;
  int tenths = 0;
  int hundredths = 0;
  
  // Separate float into digits (this needs work)
  if (number >= 10) {
    tens = (int) (number / 10);
  }
  
  number -= (tens * 10);
  
  ones = (int) number;
  
  number -= ones;

  number = 100 * number;
  if (number >= 10) {
    tenths = (int) (number / 10);
  }
  number -= (tenths * 10);
  hundredths = ((int) (number)) % 10;
  
  // Turn of display before updating data on it
  lc.shutdown(0, true);
  
  // Don't display a padding 0
  if (tens > 0) {
    lc.setDigit(0, (displayIndex * 4) + 0, tens, false);
  } else {
    lc.setChar(0, (displayIndex * 4) + 0, (byte)127, false);
  }
  lc.setDigit(0, (displayIndex * 4) + 1, ones, true);
  lc.setDigit(0, (displayIndex * 4) + 2, tenths, false);
  lc.setDigit(0, (displayIndex * 4) + 3, hundredths, false);
 
  // Turn the display back on 
  lc.shutdown(0, false);
}

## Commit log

2014-08-17 Add some arduino code for measuring voltage and current
2014-08-18 Add unfinished controller board schematic
    [controller.sch]
2014-08-18 Add microcontroller to controller board schematic (still wip)
    [controller.sch]
2014-08-19 More uC wiring + connector for controller schematic
    [controller.sch]
2014-08-23 Added coarse/fine voltage regulation opamp circuit, moved things around Just needs rotary encoder/switches implemented
    [controller.sch]
2014-08-23 Add some notes on rotary encoders/arduino after a session of experimenting
2014-08-24 Add a dual PWM precise voltage regulation arduino sketch
2014-08-24 Finished schematic
    [controller.sch]
2014-08-24 Update 7 segment display digit mapping (arduino) in accordance with schematic
2014-08-24 Tweaks to controller schematic
    Note: controller board will be split into io schematic and controller
    schematic due to Eagle's free version board area constraints.
    [controller.sch]
2014-08-24 Add io schematic, split off from controller schematic
    [io.sch]
2014-08-24 Remove IO parts from controller schematic and route to connector instead
    [controller.sch]
2014-08-24 start a board layout for io board, needs routing
    [io.brd, io.sch]
2014-09-07 Finish up controller board (including pcb)
    [controller.brd, controller.sch]
2014-09-07 Route IO board (badly)
    [io.brd, io.sch]
2014-09-14 Tighten up io board a bit, should be ready for etching
    [io.brd]
2014-09-14 add identifying text / credit on bottom layer of IO board
    [io.brd]
2014-09-20 Improve controller board design (Trace width, mounting holes, text)
    [controller.brd, controller.sch]
2014-09-21 Add power board schematic
    [power.sch]
2014-09-22 Add power board pcb design
    [power.brd, power.sch]
2014-09-26 Correct missing connector on power board `
    [power.brd, power.sch]
2014-09-27 Fix up some polygon on power board
    [power.brd]
2014-10-06 Correct mistakes in the controller opamp circuit
    - Coarse voltage multiplier from 5->16.75V now from 5->30V
    - Summing opamp was doubling voltage, now just voltage follower
    [controller.brd, controller.sch]
2014-10-06 Correct another mistake in controller board
    [controller.brd, controller.sch]
2014-10-06 Flesh out some structure for the arduino code
2014-10-07 Implement untested voltage and current reading
2014-10-08 Add screenshots of the PCB layouts in eagle
2014-10-10 Add partially tested voltage/current display implementation
2014-10-11 Measurement calibration, implement writeVoltage, tweak/fix display
    [psu_controller.ino]
2014-10-12 Implement all the things in arduino, untested.
    - Setting target voltage and current limit with rotary encoders
    - Adjusting output voltage according to targer voltage and taking into account
    current and current limit
    - Display modes for measurment and setting; when in setting, display
    will blink
    - Bunch of documenting
2014-10-14 Tweaks and fixes during hardware testing
    [psu_controller.ino]
2014-10-18 Add bunch of measurements of boards and stuff
